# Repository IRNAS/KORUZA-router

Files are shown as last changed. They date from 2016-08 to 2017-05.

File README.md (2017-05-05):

# KORUZA-router

KORUZA router is an open hardware open software development of a routing platform to be used in wireless optical system KORUZA as the control and routing platform as well as secondarily as management for wireless outdoor routers typically used in mesh networks. This repository currently serves as the ongoing requirements base for developing such a device.

# What is in this repository?
Router specification is developed using the following approach. Issues opened in this repository discuss and comment features. [Requirements](requirements.md) file implements the features from all Issues in a document to communicate with the manufacturer. Please comment in Issues or push suggested changes to requirements.

# KORUZA - Primary use-case
This router is the heart of KORUZA system and runs all applicaiton specific code, alignment algorithms and user interface. It is connected with the following:

Internally:
 * SFP module for wireless link (1G/10G data + i2c)
 * webcam (usb)
 * stepper controller+io (uart,i2c,usb)
 
Externally:
 * WiFi backup (1Gbps ethernet + PoE)
 * Secondary KORUZA unit (1Gbps ethernet + PoE)
 * User router (1Gbps ethernet + PoE)
 
# WISP/Community backbone node switch/management - Secondary use-case
Used to connect different outdoor wireless routers together and power them with added management, much like existing Ubiquiti and Mikrotik devices with such support, however being completely open, versatile and running open software with external peripherals well supported

* DC/AC input for power supply
* Fiber input for isolation
* Several network ports (1Gbps ethernet + PoE)
* Sensor input and device protection
 
## Base
The "reference" design used for this specification is MqMaker WiTi board https://mqmaker.com/ which is open hardware developed for home router application. We aim to change it for mesh routing and such type of development.

Requirements are a separate file and entries there are based on closing issues.

## Wish list
Hereby we list all the different ideas that could be included, later defined in specification if accepted. Please open an issue for every feature and we will discuss if it should be implemented or not.

* DC/AC power input
* PoE input, passive 24V or 48V
* PoE output on all ports
* PoE switch and consumption measurement per port
* Microcontroller based system watchdog, router reset circuit
* Two USB ports
* UART, I2C port
* 2 SFP ports
* 10Gbps pass-trhough between ports with retiming
* WiFi 2.4Ghz for local access
* WiFi 5GHz expansions socket
* GPIO ports
* Relay expansion
* Bluetooth for configuration and control

---

#### License

All our projects are as usefully open-source as possible.

Hardware including documentation is licensed under [CERN OHL v.1.2. license](http://www.ohwr.org/licenses/cern-ohl/v1.2)

Firmware and software originating from the project is licensed under [GNU GENERAL PUBLIC LICENSE v3](http://www.gnu.org/licenses/gpl-3.0.en.html).

Open data generated by our projects is licensed under [CC0](https://creativecommons.org/publicdomain/zero/1.0/legalcode).

All our websites and additional documentation are licensed under [Creative Commons Attribution-ShareAlike 4 .0 Unported License] (https://creativecommons.org/licenses/by-sa/4.0/legalcode).

What this means is that you can use hardware, firmware, software and documentation without paying a royalty and knowing that you'll be able to use your version forever. You are also free to make changes but if you share these changes then you have to do so on the same conditions that you enjoy.

Koruza, GoodEnoughCNC and IRNAS are all names and marks of Institut IRNAS Rače. 
You may use these names and terms only to attribute the appropriate entity as required by the Open Licences referred to above. You may not use them in any other way and in particular you may not use them to imply endorsement or authorization of any hardware that you design, make or sell.

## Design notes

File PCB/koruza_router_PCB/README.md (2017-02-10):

# Koruza router layout

Layout for koruza router is done in [Altium designer][altium_link]. Also there is [PDF documentation][pdf_docs_link] of the project. 
The free version of the Altium designer viewer can be downloaded from this [link][altium_download].

### Mandatory:
* board shape
* board dimensions
* board mounting holes
* GPIO expansion connector position
* SFP modules must have separate cages
* components that must be on the front edge of the board:
  * reset button
  * status LEDs
  * USB 3.0 connector
  * 4x Ethernet RJ45 connectors
  * 2x SFP connectors, with separate cage, because one cage would net be soldered
  * DC jack 5V

### Not mandatory:
* microSD card slot can be placed on any edge, except front edge with connectors
* console header can be placed near any another edge
* 5.08mm 2-pin screw terminal can be placed on any edge, except front edge with connectors



## Mechanical layout
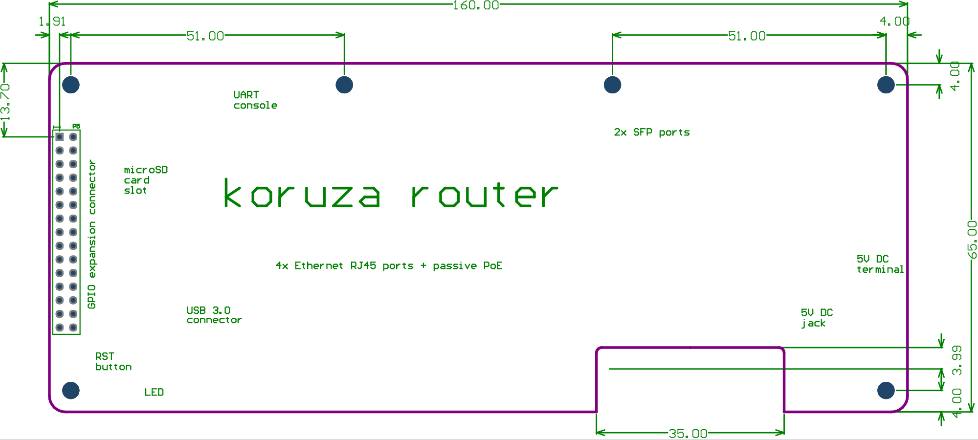
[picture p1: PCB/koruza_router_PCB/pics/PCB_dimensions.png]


[altium_link]: http://www.altium.com/
[altium_download]: http://www.altium.com/altium-designer-viewer
[pdf_docs_link]: https://github.com/IRNAS/KORUZA-router/blob/1G-router-requirements/PCB/koruza_router_PCB/Project%20Outputs%20for%20koruza_router_PCB/koruza_router.PDF

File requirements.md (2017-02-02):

# Requirements for KORUZA routing platform

 * Configuration: 6 port Gigabit router (4x RJ45 + 2x SFP) and KORUZA specific features
 * Design license: Open source hardware
 * Firmware: Openwrt trunk
 * Bootloader: U-Boot
 * Main chip: 
  * CPU: MediaTek MT7621A (integrated switch)
  * 2x GE PHY: (SerDes functionality for SFP)
   * AR8031 to RGMII port (2.2.2 Operation Mode, Fiber)
   * AR8031 to MT7621A switch port (2.2.3 Operation Mode, Media Converter)
 * RF: None
 * Flash: 32 MB
 * RAM: 256 (512 if possible) MB DDR2/DDR3
 * Hardware Watchdog: PIC10f200, 2x GPIO
 
 * Physical interfaces
  * 4x Gigabit ethernet RJ-45 with LED
    * Gigabit passive PoE conections: positive + 4,5, negative - 7,8
    * Each ethernet port power lines connected to expansion header, [connection diagram](https://github.com/IRNAS/KORUZA-router/blob/1G-router-requirements/PCB/koruza_router_PCB/pics/GPIO%20expansion%20connector%20pinout.png)
  * 2x external SFP port with cage with LED
  * 1x USB 3.0 connector external
  * 1x MicroSD card connector
  * GPIO expansion connector (30pin 2.54mm, 2x15 dual row), [connection diagram](https://github.com/IRNAS/KORUZA-router/blob/1G-router-requirements/PCB/koruza_router_PCB/pics/GPIO%20expansion%20connector%20pinout.png)
    * 1x USB 2.0
    * 2x I2C
    * 2x UART
    * 5V power
    * GPIO pins
    * PoE pins
  * Console UART (4 pin 2.54mm)
  * Push button reset (same as Mqmaker WiTi)
  * 2x status LED, software controllable (can be switched off in software), all LEDs must be visible from the connector edge of the router
  * Connector layout [see image for details](https://github.com/IRNAS/KORUZA-router/blob/1G-router-requirements/PCB/koruza_router_PCB/Project%20Outputs%20for%20koruza_router_PCB/koruza_router.PDF)
 
 * Power
  * Input: Gigabit Ethernet power pins connected to expansion connector
  * Input: 5.08mm 2-pin screw terminal + DC barrel jack for 5V + 5V power pins on expansion connector
  * Consumption: TDB (estimated 7-10W with 1 SFP module active)
  
 * Environmental & Mechanical
  * Temperature range:
   * Operating: -20 to +80 °C
   * Storage: -20 to +80 °C
  * Humidity: 5%-90% typical
  * Dimensions: 65mm x 160mm (with 3mm mounting hole in each corner)
  * Enclosure: none
  * Weight: TBD
   
 * Reliability
  * ESD: Conductive 4 kV, Air 8 kV
  * Surge protection: gas discharge arrestors on all RJ-45 ports (subject to cost)
  * MTBF: Over 50000h
   
 * Compliance standard:
  * CE Mark for standalone sales
  * FCC
  * RoHS
   
# Detailed features and implementations - Main router board
Describes specifics for hardware implementation and design requirements on a technical level. The overall KORUZA system consists of 2 standalone boards: Main router board, Koruza board (power supply + KORUZA control). Hereby we are specifying router board only.

## SFP interface
There are two SFP port, one is with cage facing the connector edge of the board, and one is internal. The internal SFP port is without the cage, but he will be also facing the connector edge of the board and have space for the cage to be soldered if needed.

 * SFP ports
  * external SFP (marked A) (1Gbps) with cage via PHY to RGMII port (RGMII - WAN2 as marked on MqMaker WiTi)
  * internal SFP (marked B) (1Gbps) with cage (do not install it) via PHY to switch port (port P4 - WAN as marked on MqMaker WiTi)

The implementation of SFP ports must comply with SFP MSA standard and power supply must be filtered according to specification.

## I2C Mux
Because the main CPU has only one I2C bus, there is a need for some kind of multiplexing because of two SFP ports. The additional requirement is to have I2C of internal SFP port also on the expander connector like shown in the diagram below.

## Power supply
The main router board operates at 5V power and has a respective input for 5V. PoE functionality is implemented as separate Power supply board that connect though a GPIO expansion connector. 

## Mehanical design
All necessary mechanical design requirements for Koruza router can be found in the [PCB part of the repository](https://github.com/IRNAS/KORUZA-router/tree/1G-router-requirements/PCB/koruza_router_PCB).



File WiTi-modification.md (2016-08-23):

# MqMaker WiTi board modification

For prototyping of KORUZA v2 https://mqmaker.com/doc/WiTi/ WiTi board is used, but requires a number of modifications as follows:

Remove components:

* RP-SMA antenna connectors
* Power connectors for SATA
* SATA connectors
* Diode D1 (Disables RTC and clears I2C address 0x50)
* Diode D2 (Disables RTC and clears I2C address 0x50)

## PoE modification (802.3af Mode B)
Passive gigabit PoE can be added to WiTi board by modifying the board and adding an external step-down regulator. Ethernet poinout for Ubiquiti gigabit PoE injectors 2-Pair Powering (model POE-24-24W) is +(4,5)pins, (7,8) pins and gigabit 4-Pair Powering (model POE-24-24W-G) is +(1,2)(4,5)pins, -(3,6)(7,8) pins. Note that if you use PoE without removing reistors, you will burn them, but nothing else bad should happen.

### PoE modification 2-pair
Remove resistors on the port(s) for 2-pair PoE for gigabit operation, TAP on magnetics needs to be used. Then add a wire to the pad of the resistor that is oriented towards the ethernet connector.

* LAN0 (SW0), remove R303 (DC-), R302 (DC+)
* LAN1 (SW1), remove R313 (DC-), R312 (DC+)
* LAN2 (SW2), remove R323 (DC-), R322 (DC+)
* LAN3 (SW3), remove R333 (DC-), R332 (DC+)
* WAN0 (SW4), remove R343 (DC-), R342 (DC+) (KORUZA default)
* WAN1 (SW5), remove R798 (DC-), R797 (DC+)

### PoE modification 4-pair
Remove resistors on the port(s) for 4-pair PoE for gigabit operation, TAP on magnetics needs to be used. Then add a wire to the pad of the resistor that is oriented towards the ethernet connector.

* LAN0 (SW0), remove R303 (DC-), R302 (DC+)
* LAN1 (SW1), remove R313 (DC-), R312 (DC+)
* LAN2 (SW2), remove R323 (DC-), R322 (DC+)
* LAN3 (SW3), remove R333 (DC-), R332 (DC+)
* WAN0 (SW4), remove R343 (DC-), R342 (DC+) (KORUZA default)
* WAN1 (SW5), remove R798 (DC-), R797 (DC+)

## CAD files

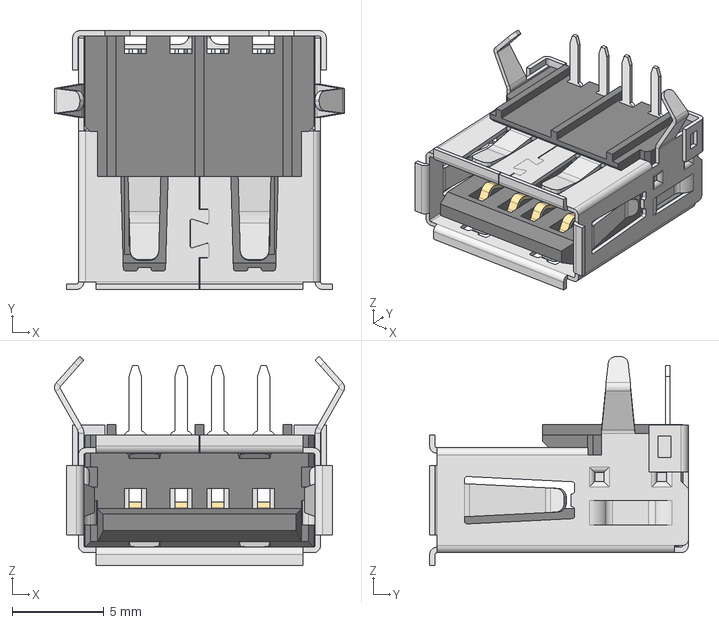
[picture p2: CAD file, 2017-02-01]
PCB/koruza_router_PCB/step models/USB_A.stp
15.8 x 14.1 x 11.4 mm

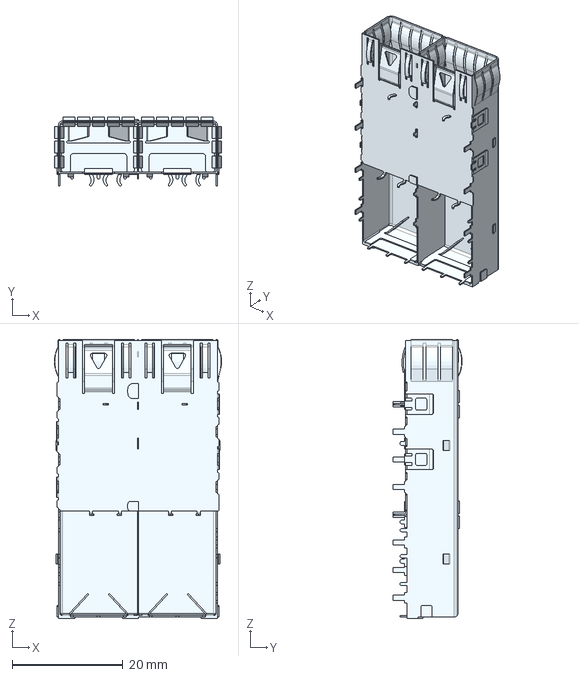
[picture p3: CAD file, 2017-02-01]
PCB/koruza_router_PCB/step models/SFP_dual.stp
30.2 x 12.5 x 50.4 mm

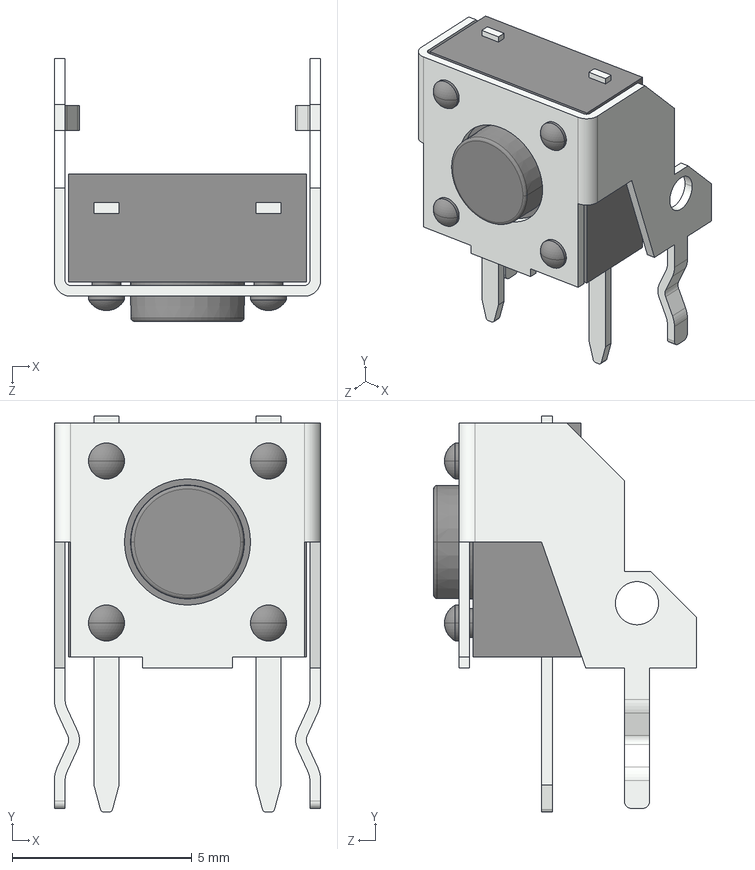
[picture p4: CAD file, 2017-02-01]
PCB/koruza_router_PCB/step models/SWITCH, TACTILE, RIGHT ANGLE, 12VDC, 50MA, 3_15MM ACTUATOR, WEALTH METAL TC-0240Z.step
7.40 x 11.0 x 7.30 mm

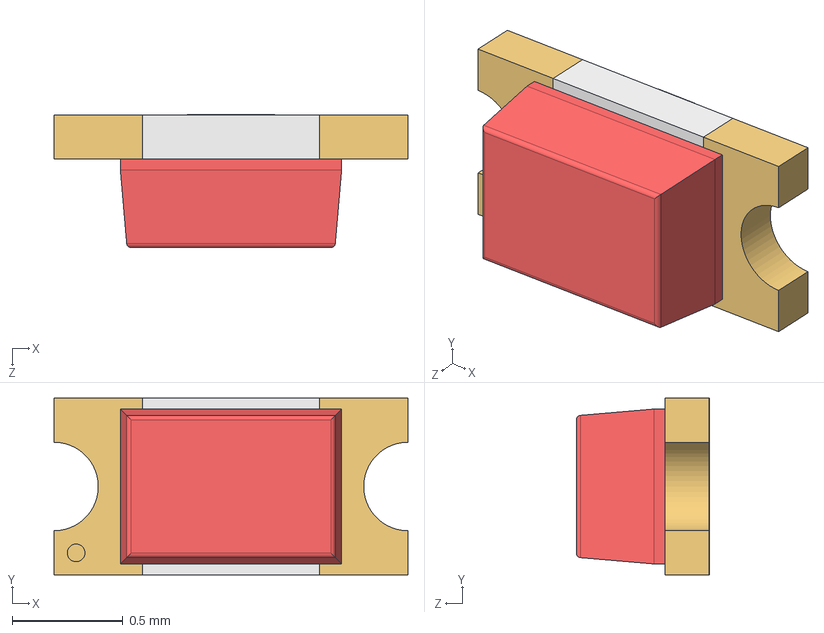
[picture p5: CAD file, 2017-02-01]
PCB/koruza_router_PCB/step models/LED_0603_R.STEP
1.60 x 0.8 x 0.602 mm
User Library-LED_0603_R_Pocket002
User Library-LED_0603_R_Pad004
User Library-LED_0603_R_Fillet
User Library-LED_0603_R_Pocket001
User Library-LED_0603_R_Pad

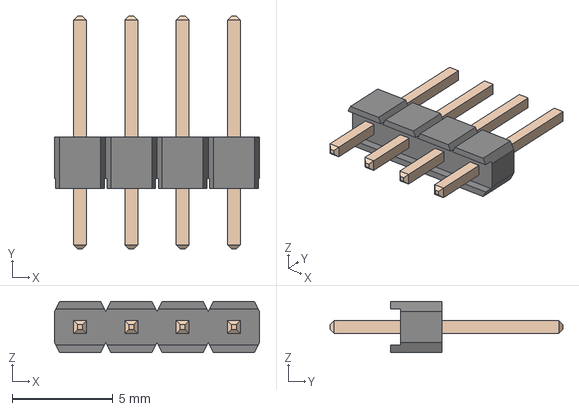
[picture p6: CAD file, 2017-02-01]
PCB/koruza_router_PCB/step models/header_4pin_TH.stp
10.2 x 11.5 x 2.54 mm

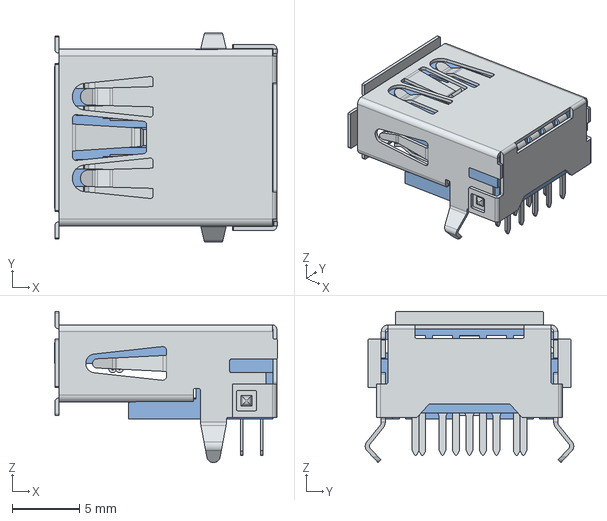
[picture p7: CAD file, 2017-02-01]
PCB/koruza_router_PCB/step models/USB A 3_0.stp
16.6 x 15.5 x 11.2 mm

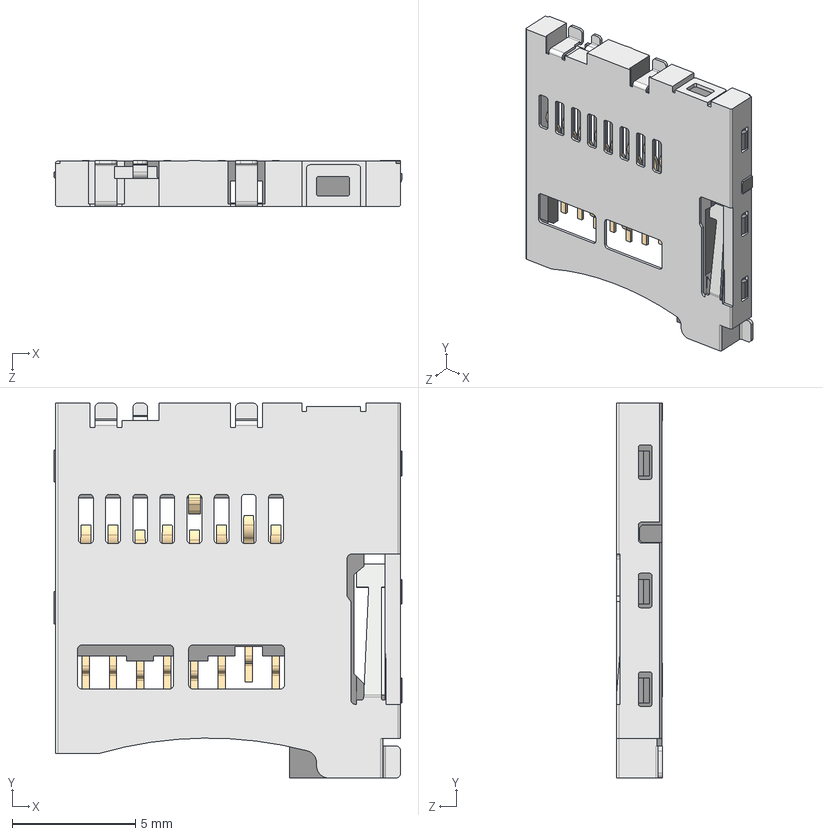
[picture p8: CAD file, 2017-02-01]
PCB/koruza_router_PCB/step models/microSD_socket.step
14.1 x 15.2 x 1.88 mm

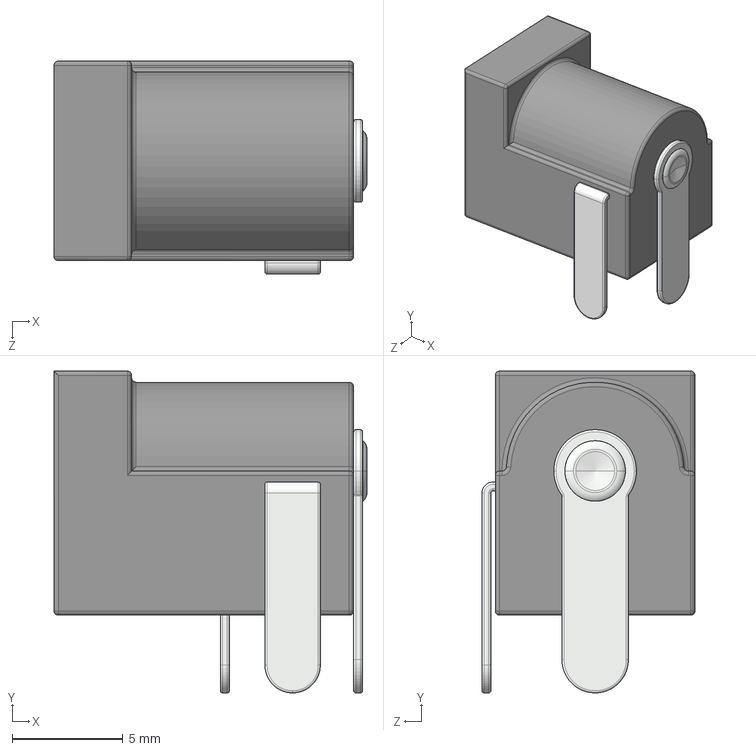
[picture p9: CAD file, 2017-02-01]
PCB/koruza_router_PCB/step models/DC_JACK_10A.step
14.1 x 14.5 x 9.60 mm

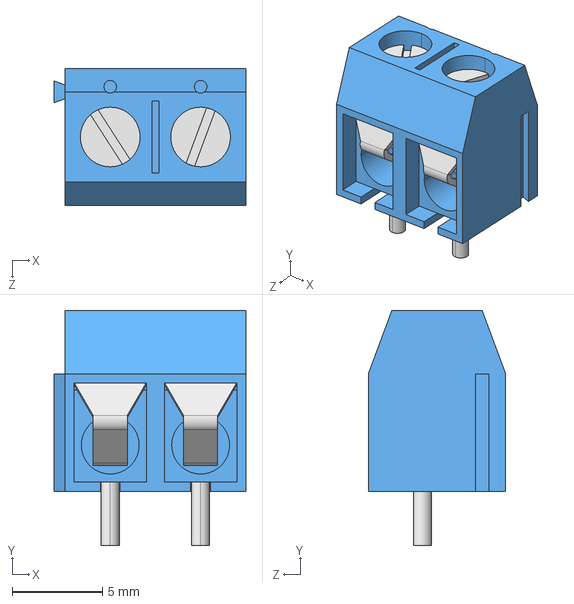
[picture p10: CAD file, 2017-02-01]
PCB/koruza_router_PCB/step models/Terminal-Screw-3A-2way (1).step
10.6 x 13.0 x 7.60 mm

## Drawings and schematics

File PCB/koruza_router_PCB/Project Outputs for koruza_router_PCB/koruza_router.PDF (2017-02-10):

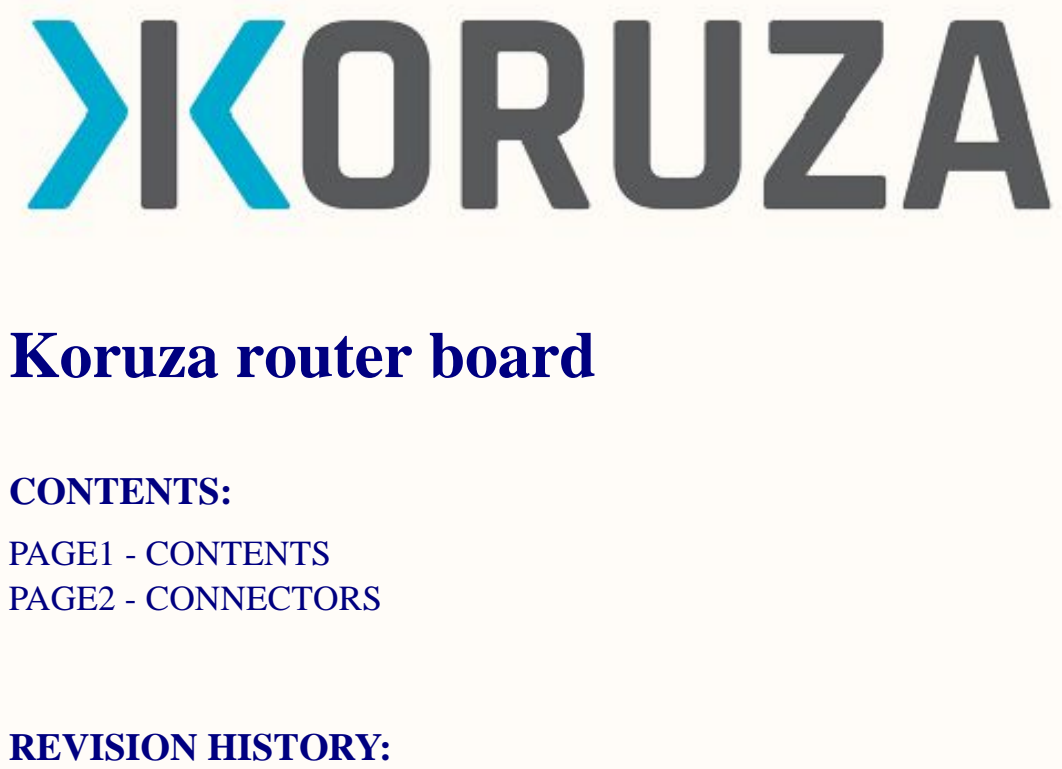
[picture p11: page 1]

Title
Koruza 2.0 high speed add on board

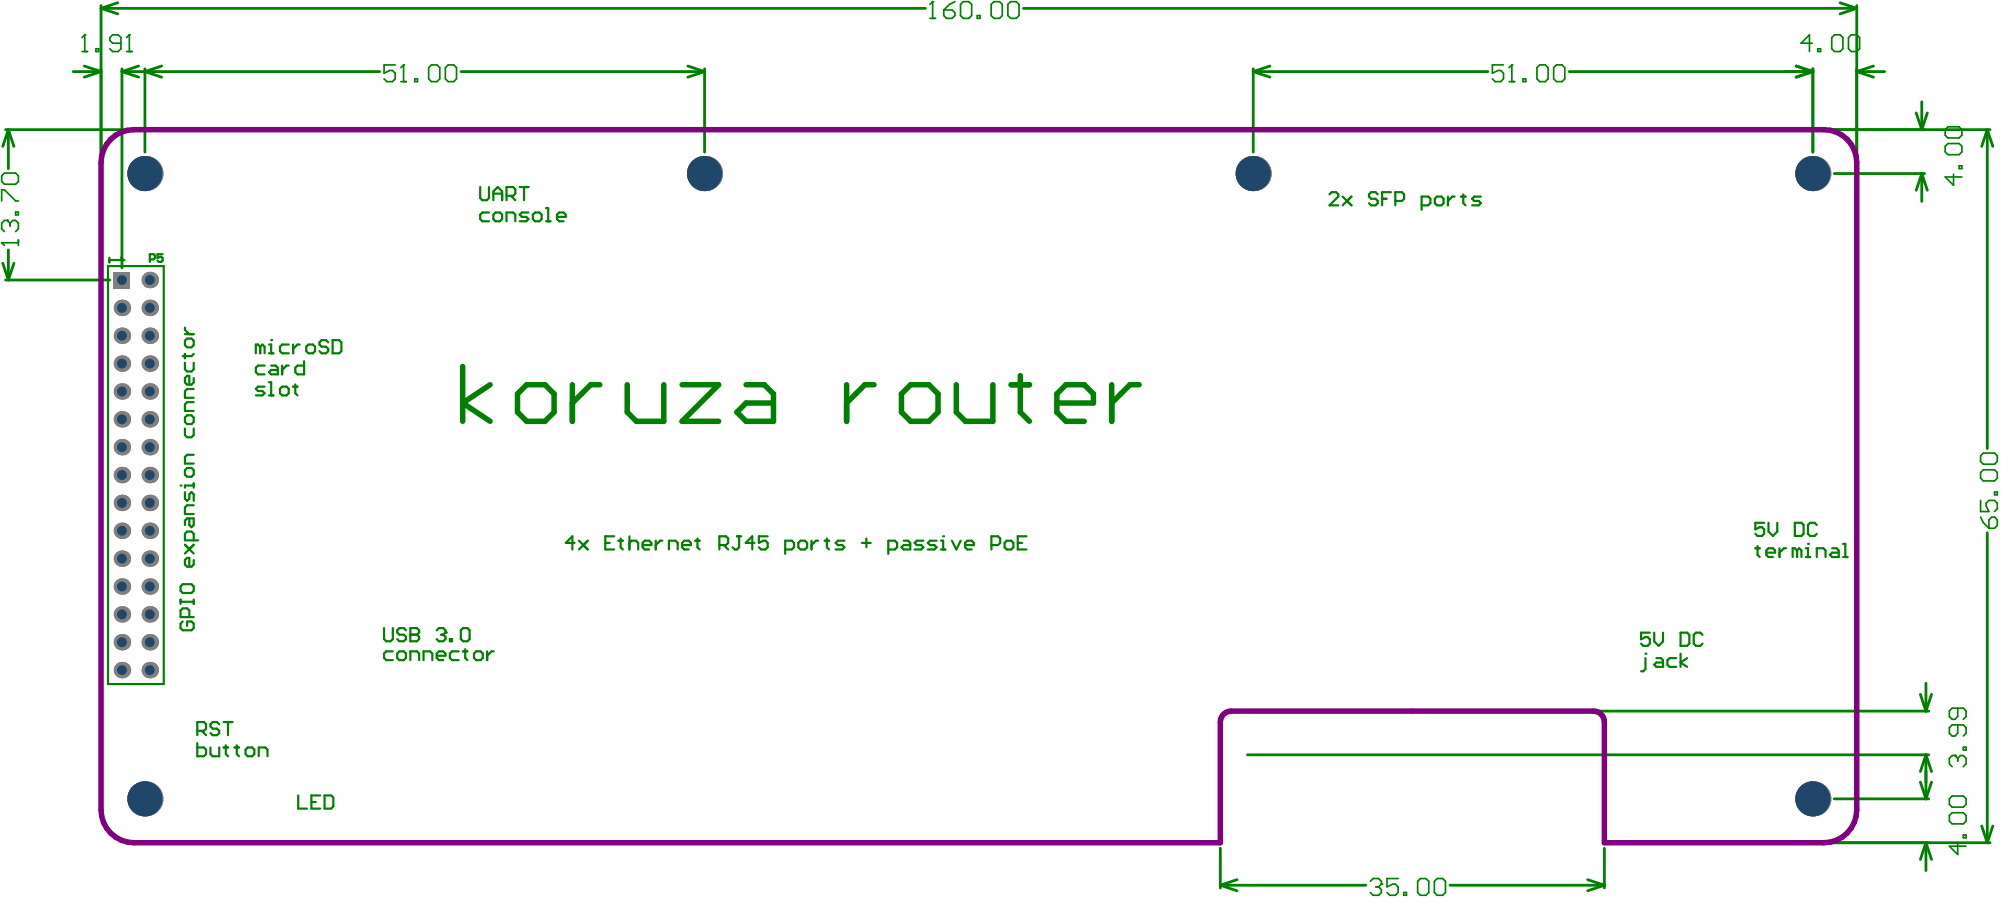
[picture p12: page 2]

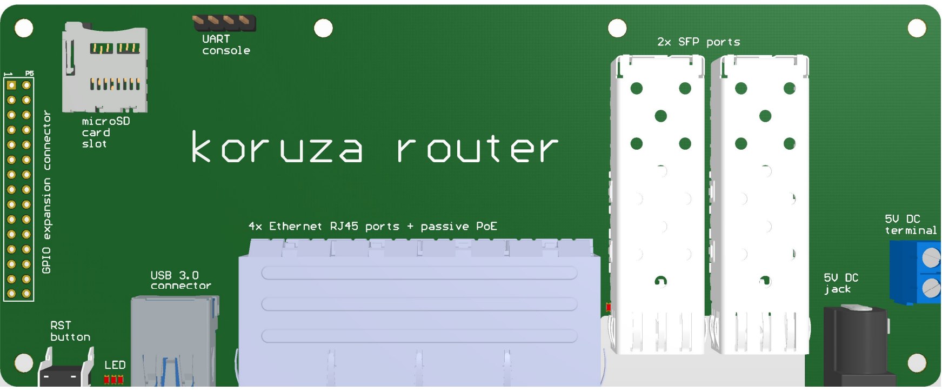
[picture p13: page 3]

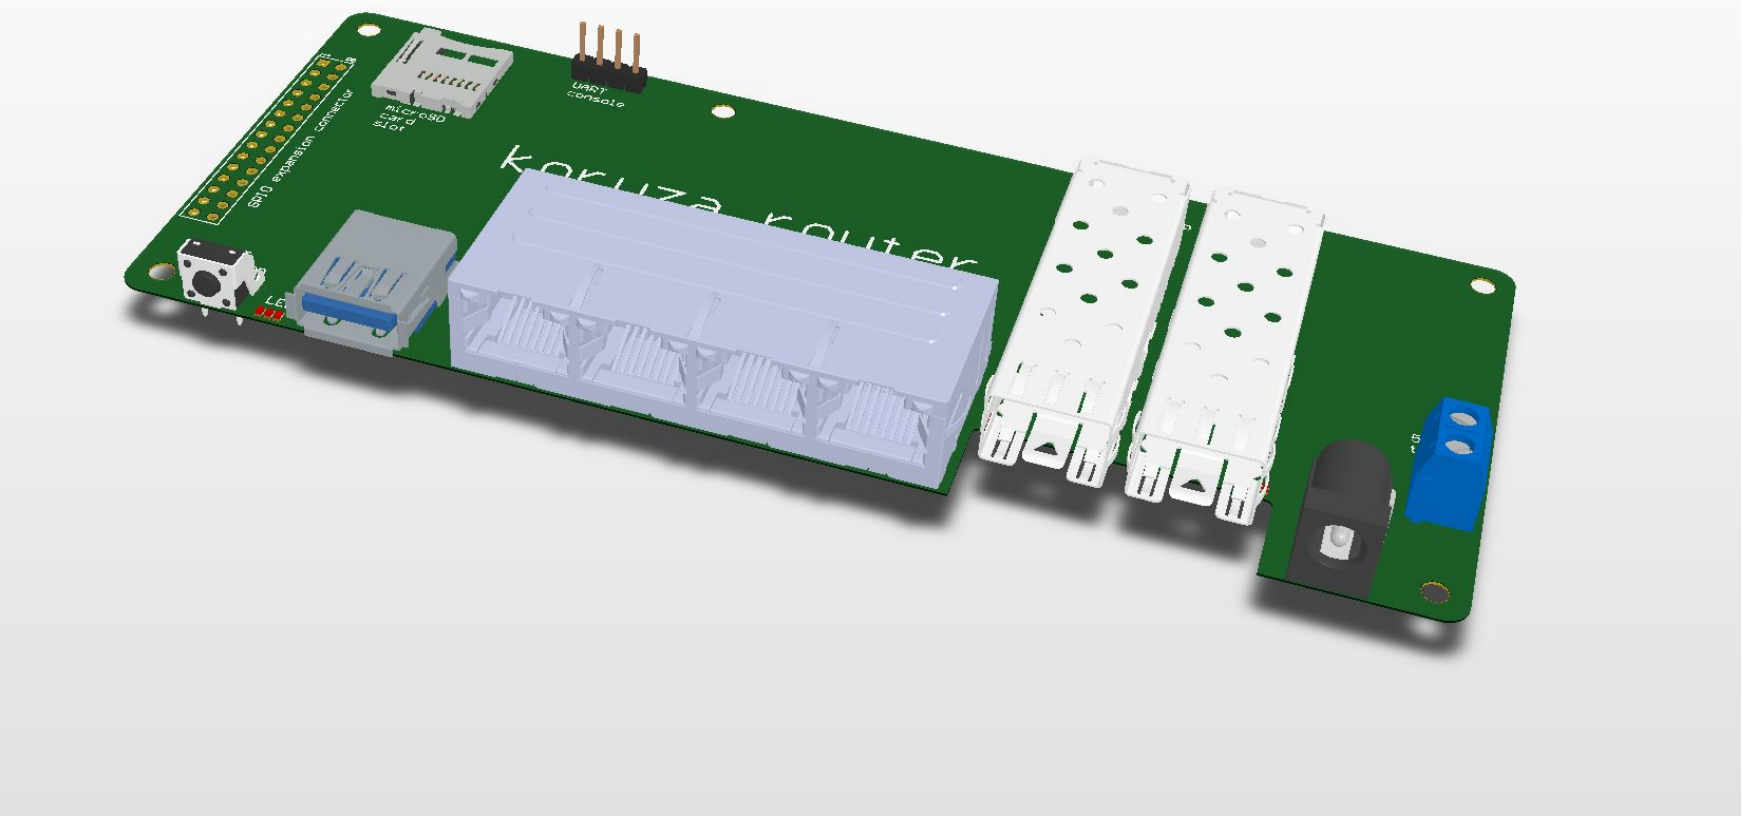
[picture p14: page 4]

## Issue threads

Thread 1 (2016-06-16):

Processor choice (MT7621 or different...)

SloMusti, 2016-06-16:
Choosing the core processor is key to cover all features, the choice is somewhat limited to Mediatek chips that are well supported already no no significant work on supporting them in openwrt is required.

MT7621: https://wikidevi.com/wiki/MediaTek_MT7621
- MT7621AT
  - 5xGbE, 1xRGMII, 3xPCIe, 1xUSB 3.0, 2xUSB 2.0,
  - L1-32/32kB, L2-256kB, DDR2/DDR3 256/512MB, LFBGA346
- MT7621ST
  - 5xGbE, 1xRGMII, 3xPCIe, 1xUSB 3.0, 2xUSB 2.0,
  - L1-32/32kB, L2-256kB, DDR2/DDR3 256/512MB
- MT7621NT
  - 2xRGMII, 2xPCIe, 1xUSB 3.0, 2xUSB 2.0,
  - L1-32/32kB, L2-256kB, DDR2 256MB

VojislavM, 2016-11-16:
Processor is Mediatek [MT7621AT](https://wikidevi.com/wiki/MediaTek_MT7621), it is the main processor on [WiTi board](https://mqmaker.com/product/witi-board/)

SloMusti, 2016-11-16:
MT7621NT is not suitable due to the lack of internal switch

VojislavM, 2016-11-16:
Ideas for the board and processor: https://forum.openwrt.org/viewtopic.php?id=59092&p=2

Closed 2016-11-16.

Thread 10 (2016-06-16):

Power supply

SloMusti, 2016-06-16:
The board must be powered primarily via PoE for KORUZA application, but should have input for AC/DC power in the secondary application.

Power input must be sufficient to power unit itself with KORUZA periphery as well as one more router and KORUZA unit through PoE output ports.

SloMusti, 2016-06-16:
Power input DC jack should be on the board or at least a pad for adding it later on interchangeably with a screw terminal connector.

VojislavM, 2016-11-17:
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

SloMusti, 2016-11-17:
Power input to the router will be 5V regulated, external power board is used for PoE. Above connector is placed on the router to connect to an external power board.

VojislavM, 2016-11-17:
Power connector V2, ground is common.
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

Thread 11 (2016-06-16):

PoE input

SloMusti, 2016-06-16:
PoE input should primarily support passive 24V DC with gigabit support, much like Ubiquiti equipment with  POE-24-24W-G injector. Due to recent advances in equipment and power requirements 48-50V input via passive PoE should be supported if possible or at least implemented such that one can add an external regulator.

VojislavM, 2016-11-18:
Passive PoE in/out for every RJ-45 port

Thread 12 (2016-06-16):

PoE output

SloMusti, 2016-06-16:
Power over ethernet should be supported on all ports, even on input for up to 24V out with possible modification for higher voltage devices.

PoE output per port should support:
 * per channel switching
 * per channel current measurement
 * possibly auto-load detection

SloMusti, 2016-06-29:
Heater element may be powered through PoE output as well since not all network ports are used for KORUZA. Add a header on the PCB with power lines prior to Ethernet connector

VojislavM, 2016-11-18:
Passive PoE in/out for every RJ-45 port

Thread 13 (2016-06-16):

GPIO ports

VojislavM, 2016-06-16:
GPIO pins are useful for expansion port so the router board can interact with the real world using some kind of expansion boards, like relay board, display board, additional sensor boards, etc. Koruza unit needs GPIO ports for LED indicators. Thay are useful to tell the user if everything is working ok.

Closed 2016-11-18.

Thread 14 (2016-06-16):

AC/DC input

SloMusti, 2016-06-16:
For use in secondary application, a robust AC/DC rectified input should be put in place as it has been show it is best practice to do so when using equipment of towers and other lightning prone locations.

This is bulky and should be an expansion board if required, likely connecting to #10 DC jack for input.

SloMusti, 2016-11-17:
Optional for use on the external power board, not included on the router board itself.

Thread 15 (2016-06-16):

LED indicators

SloMusti, 2016-06-16:
Add LED indicators, such that user can clearly see what is going on. The following indicators are needed:

 * per network port (ethernet or SFP) for activity
 * power
 * system activity (possibly RGB)
 * general purpose (KORUZA link state or similar)

SloMusti, 2016-11-17:
LED indicators should be built into the ethernet port itself, added next to the SFP port and general purpose indicators should be on the board edge, such that they can be viewed from the connector side.

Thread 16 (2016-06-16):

Openwrt support

SloMusti, 2016-06-16:
The developed board must be supported in Openwrt project.

SloMusti, 2016-11-17:
MT7621A is Openwrt trunk supported using the specific implementation of Mqmaker WiTi board. The key concern is adding or using a suitable Ethernet PHY IC for SFP communication that can be OpenWRT/LEDE supported and is used via RGMII interface.

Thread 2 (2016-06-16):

SFP port

SloMusti, 2016-06-16:
To implement the SFP port, switch or ethernet PHY must have SerDes interface. Processor chips with integrated switch generally do not have this, standalone PHY is required for this.

IP1001 Integrated 10/100/1000 Gigabit Ethernet Transceiver used in MqMaker WiTi does not support this, alternative choice is required.

Possible choice is AR8033 or AR8031 are suitable choices, likely a number of other ICs.

SFP port required I2C interface to be connected to router. If there are more SFPs, I2C must be MUXed or have multiple ports

VojislavM, 2016-11-18:
* SFP ports
  * external SFP+ (marked A) (1Gbps or 10Gbps) with cage, connected to multiplexer that switches it to:
   * SerDes PHY and then to CPU via RGMII port
   * secondary SFP connector without cage
  * internal SFP (marked B) (1Gbps only), connected to SerDes PHY and then CPU directly to switch, without cage
  * internal SFP+ (marked C) (1Gbps or 10Gbps) without cage, connected to multiplexer

Check the [requirements.md](https://github.com/IRNAS/KORUZA-router/blob/master/requirements.md)

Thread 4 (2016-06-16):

USB port

SloMusti, 2016-06-16:
USB port 2.0 is required. One port for webcam one port for control board in KORUZA specific application. There is also USB 3.0 option on MT7621 which could be implemented, but likely not required in given specifications. If cost is low 3.0 port should be available outside and 2.0 port internally on GPIO header or some socket as on MqMaker WiTi.

Implementation depends on #1

VojislavM, 2016-06-16:
USB connection could be done with dual USB connector. This way we would save space on the board, and if the board is used outside of the Koruza unit, we will still have two USB connectors, which is good for the development.
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

We should pay attention to the footprint of the USB connector, so it could be replaced with the differnt connector when a board is placed inside of the Koruza unit.

SloMusti, 2016-11-16:
We will use one external USB 3.0 port facing the same way as ethernet ports and one internal on the expander board.

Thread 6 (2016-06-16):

WiFi 2.4GHz

SloMusti, 2016-06-16:
WiFi 2.4GHz is desired for local management and access in KORUZA application when installing the unit and in secondary use-case for various use-cases. Should be implemented on-board.

SloMusti, 2016-11-16:
WiFi 2.4Ghz can be added via USB if needed for admin purposes.

Closed 2016-11-16.

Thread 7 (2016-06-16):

WiFi 5Ghz

SloMusti, 2016-06-16:
WiFi at 5GHz could be added, however has somewhat limited use-case as the units are designed to be a routing platform in all use-cases with antenna+router combinations used for backup in KORUZA case of for networking in secondary use-case.

Possibly mini pci port could be added for external radio.

SloMusti, 2016-11-16:
No WiFi to be included, to have an RF free system.

Closed 2016-11-16.

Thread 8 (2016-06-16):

Serial communication (UART, SPI, I2C...)

VojislavM, 2016-06-16:
Serial ports:
- UART is required for communication with the driver board (stepper motors, ir_link, laser...), also it is useful for serial console (debugging) of the router board
- I2C is necessary because there is communication with SFP modules
- SPI is not that important, but it is good to have on some kind of expansion connector for some further upgrades.

SloMusti, 2016-11-17:
Due to two SFP ports on the board, I2C multiplexing is required.

Closed 2016-11-18.

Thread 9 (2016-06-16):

Certification and compliance

SloMusti, 2016-06-16:
Check and determine what certification is required for the device. WiFi radios are likely the critical parts #7 #6 , then complying to SFP #2 MSA agreement to talk to SFP modules correctly.

SloMusti, 2016-11-17:
No radio devices will be present on the router and thus certification is simplified. CE and RoHS are required.

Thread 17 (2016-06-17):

Hardware watchdog

VojislavM, 2016-06-17:
Hardware watchdog timer is useful. Current CPU that we have in mind has hardware watchdog timer. A user space daemon to co-work with ralink watchdog hardware. When this program started, it will wake up the watchdog hardware, and it feeds the hardware every second. If watchdog program failed to function under some situations (like kernel oops, panic) , the system will be reset by watchdog hardware. Usage: watchdog & # silent daemon
[link1](http://www.03964.com/read/1a7e18e44d52e250ab73b3ef.html)

SloMusti, 2016-11-17:
Implementation of the hardware watchdog to be determined later on, discussed with the manufacturer.

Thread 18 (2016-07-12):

Standalone power board

SloMusti, 2016-07-12:
Due to decreasing the form-factor and adding more versatility and upgrading on the power side, the voltage regulation and PoE features should be on a standalone board. #12 #11 #10

This enables the system to be later on upgraded to 48V input, 802.11af standard or similar and be more feature friendly.

I2C communication should pass from this board to router for management. And router should receive 5V directly form this board.

SloMusti, 2016-10-27:
Evaluate adding a battery power/UPS functionality to the power board with a single lipo battery.

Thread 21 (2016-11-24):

Determine why the WAN port doesn't work

kostko, 2016-11-24:
It could be either the PHY or the RGMII support in the Linux kernel as a proprietary driver from MediaTek is required for this port to work (for OpenWrt there is [this heavily modified fork](https://forum.mqmaker.com/t/alternative-openwrt-mtksdk-build-for-the-witi-board-wip/272) where and old kernel version is used to get the proprietary module to load).

We should ask the MQmaker guys if they know what exactly is the problem (we may be able to change the PHY).

SloMusti, 2016-12-01:
They are claiming the Mediatek driver needs to be simply ported to openwrt for RGMII port and that is it.

kostko, 2016-12-01:
Do they have the source code? Or how do they think it "needs to be simply ported"?

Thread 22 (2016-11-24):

Add user-accesible serial console

kostko, 2016-11-24:
Perhaps using a RJ45 connector similar to Mikrotik devices.

VojislavM, 2017-02-02:
There will be one 4 pin header for the serial console.

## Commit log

2016-11-30 i2c mux update
2016-12-01 Removed requirements for standalone power board
2017-02-01 altium project init
    [PAGE1 - CONTENTS.SchDoc, PAGE2 - CONNECTORS.SchDoc, koruza_router_PCB.PrjPcb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]
2017-02-01 pcb update
    [DC_JACK_10A.step, LED_0603_R.STEP, SFP_dual.stp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]
2017-02-01 pcb and docs update
    [koruza_router_PCB.PrjPcb]
2017-02-10 separate sfp cage change
    [koruza_router_PCB.PrjPcb]
2017-02-15 Updated GPIO to add router power
2017-02-15 Added GPIO expansion connector pinout.png
